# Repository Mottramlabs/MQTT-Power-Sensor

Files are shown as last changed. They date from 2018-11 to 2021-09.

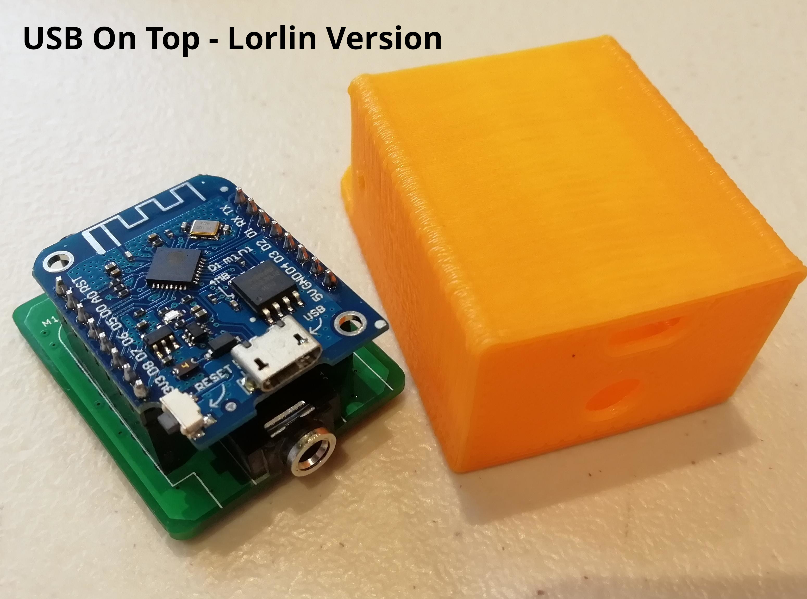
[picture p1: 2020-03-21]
3D case/Lorlin.jpg

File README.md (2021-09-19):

## ESP8266 - Power Sensor (Using a Wemos D1 Mini)

The sensor PCB uses a split core current transformer (CT) to sense the AC current flowing through a mains cable, a typical CT would be the SCT-013-000 (Current Type) capable of measuring up to 100A  available on eBay. The current transformers output is applied to a burden resistor (22 ohm) which is biased at around half of the ESP8266's supply voltage (3.3V). The ESP8266's own A/D is then used to measure voltage developed across this burned resistor.  The A/D used in the ESP8266 has an input voltage range of 0-1V but the Wemos adds a resistor divider to allow for a 0-3.3V input range to the Wemos board. 

Included are the PCB files with schematic, a simple 3D printable case and some sample firmware for the ESP8266.

###### Firmware Version 1

Using the ESP8266's own A/D (10-bit) to measure the output of the current transformer, this version measure the peak values of the mains sine wave then calculating the RMS voltage value.

###### Firmware Version 2

This is based of the EmonLib https://github.com/openenergymonitor/EmonLib library. This works different from version 1 and as some digital filtering which improves resolution at lower power levels.

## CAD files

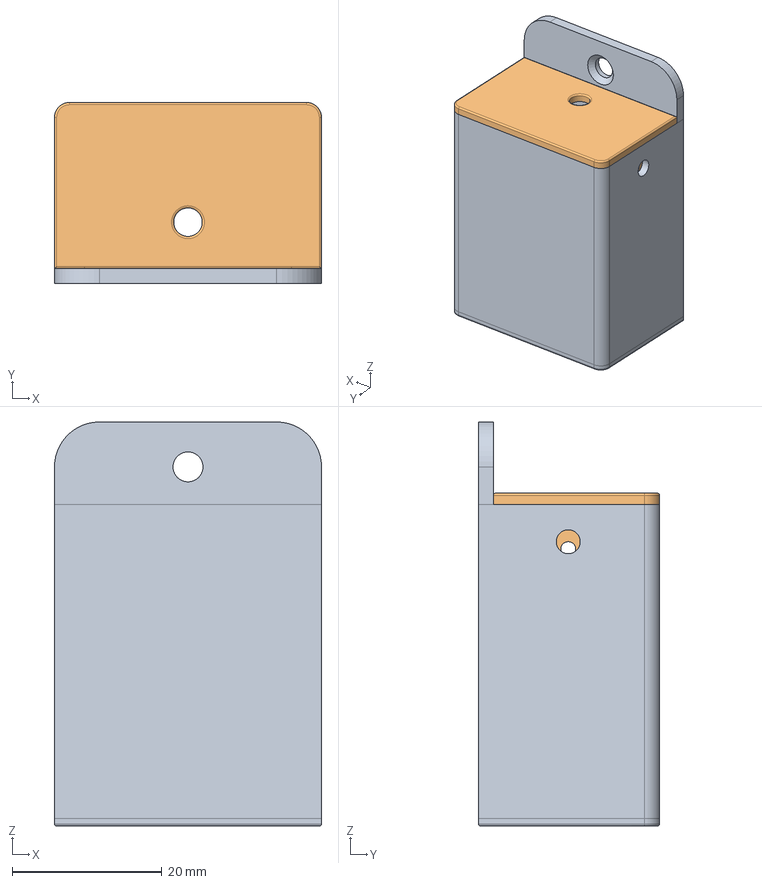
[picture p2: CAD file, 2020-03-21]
3D case/Power Sensor Lorlin Type V1.fcstd
35.7 x 24.2 x 54.0 mm
Body - Case
Body - Lid

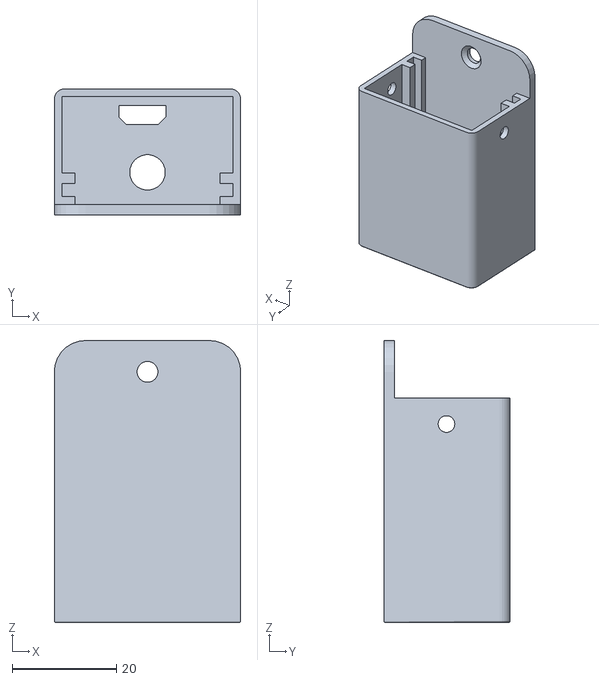
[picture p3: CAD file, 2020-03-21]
3D case/Box Lorlin Version.stl
35.7 x 24.2 x 54.0

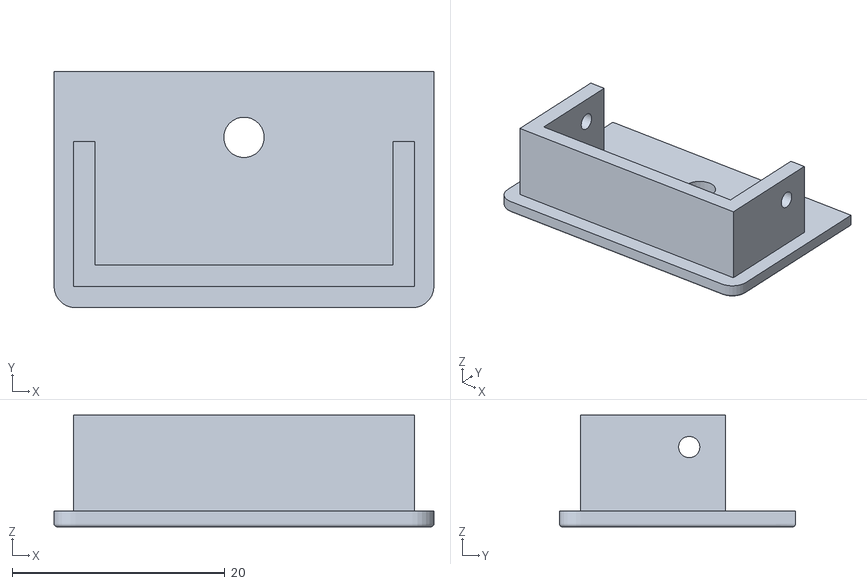
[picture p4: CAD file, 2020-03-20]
3D case/Lid.stl
35.7 x 22.2 x 10.5

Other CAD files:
3D case/Box.stl
3D case/Power Sensor V1.fcstd

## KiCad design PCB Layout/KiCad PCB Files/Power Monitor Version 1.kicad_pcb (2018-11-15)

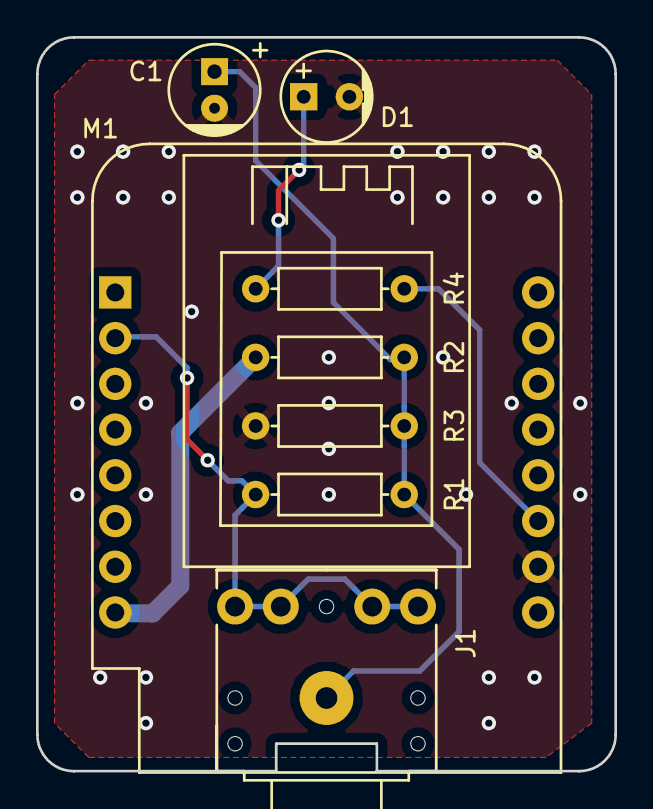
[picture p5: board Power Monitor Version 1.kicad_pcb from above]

Board: 2 copper layers, 32.1 x 40.8 mm, 8 parts (0 on the bottom side), 6 nets.

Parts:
C1: 10uF 10V; Cap_5mm_THT
D1: LED; LED 5mm
J1: 3.5mm Jack Socket - PJ-307; Jack_3.5_PJ-307
M1: Wemos_D1_Mini; Wemos D1 Mini
R1: 22R; Resistor_THT
R2, R3: 10K; Resistor_THT
R4: 1K; Resistor_THT

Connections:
+3V3: M1.8, R2.1
GND: C1.2, D1.2, M1.10, R3.2
unnamed: C1.1, J1.1, R1.2, R2.2, R3.1
unnamed: D1.1, R4.2
unnamed: J1.2, J1.3, J1.4, J1.5, M1.2, R1.1
unnamed: M1.11, R4.1

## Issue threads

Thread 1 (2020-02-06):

Board LED vs built in LED

bchris999, 2020-02-06:
On the Wemos D1 mini (recommended board), the build in LED on the wemos is on pin D4. This pin needs to be high for the onboard to be off.
The schematic has the LED on the board also on D4, however the pin need to be high for this LED to be on.
This, in effect, means that the LED on the board will be the opposite of the wemos LED.
Is this by design? Considering the availability of other (unused) pins on the Wemos.

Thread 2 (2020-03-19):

Enclosure USB cut out does not line up

neilrees, 2020-03-19:
I'm not sure if all D1 Mini boards are made equal, but the Wemos Lolin D1 Mini has the micro-usb port mounted on the top of the board when the A0 pin is on the left and D4 is on the right, the orientation required by the Power Sensor PCB.

In that orientation the micro-usb port does not line up with the cut out in the enclosure, the cut out lines up with where the port would be if the USB port were on the bottom of the board.

Would it be possible to add the CAD files for the enclosure to the repository to allow for easier editing?

Mottramlabs, 2020-03-19:
Hi Neil
Is this the board https://docs.wemos.cc/en/latest/d1/d1_mini.html ? It
appears the USB socket is on the opposite site to the D1 boards I have been
using.
The case was done using Freecad, I'll upload the files to Github and
Thingiverse.
Regards
David

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

neilrees, 2020-03-19:
Yes that's the exact one.
Much appreciated.  I'll see if I can flip the port over, if I can I'll send you a Pull Request.

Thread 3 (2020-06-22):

Getting nothing but 11w readings

beercity, 2020-06-22:
I just get 11W on the basic test sketch no matter what.
If I connect the CT, I get 11w, if I disconnect I get 11W.
If I remove the Wemos from the sensor board, still 11W

Sometimes I get 23W.  But mostly 11W, and never anything besides these two.

Board issue? Code issue? Not sure.

Mottramlabs, 2020-06-23:
Hi beercity
I'm assuming you are using the basic test sketch and the 11 is in fact 0.11 Amps. That is the softwares quiescent value (which can be trimmed to zero in the code). Anyway this is what you would see if there is no current flow through the CT or it's not plugged in. You can check the signal from the CT with a multimeter set to AC volts connected across R1 the 22R burned resistor, typical values would be 169mV AC when a load of around 4.5A is present, only approximate value without calibration.
Don't forget that the CT should be clamped across only one of the wires under test, either L or N but not both as this cancels out the signal.
David

sw1970, 2021-03-13:
Hi Mottramlabs, when you say "can be trimmed to zero in the code", do you simply mean subtract the quiescent value from the measured amount? Thanks!

Mottramlabs, 2021-03-15:
Hi sw1970
Yes you are correct, simply subract the quiescent value from the sensor. Simple way is to remove the CT from the wire under test.
David

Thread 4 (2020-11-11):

SCT-013-000 YHDC 30A 1V

excogitation, 2020-11-11:
Since I am after three tries ordering the SCT-013-000 YHDC 30A 50mA version unfortunately now the proud owner of 3 SCT-013-000 YHDC 30A 1V I was wondering if that can also be put to use through some adaption or if I simply have to get the right SCT-013 variant?

Mottramlabs, 2020-11-12:
Hi Christian

As I understand it this has the burned resistor built in, so on the PCB we
can simply remove R10, R11, R1 and R12 (the burden resistors for the
30/50mA type). I don't know the value of the internal burden resistor so
the calibration would need to be changed, but should work fine.

I have ordered one of this CT's to test.

PCB schematic

https://www.mottramlabs.com/pdf/SCH201077.pdf

Regards

David

On Wed, 11 Nov 2020 at 22:48, Christian Stöveken <notifications@github.com>
wrote:

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

edekeijzer, 2022-04-09:
> Hi Christian As I understand it this has the burned resistor built in, so on the PCB we can simply remove R10, R11, R1 and R12 (the burden resistors for the 30/50mA type). I don't know the value of the internal burden resistor so the calibration would need to be changed, but should work fine. I have ordered one of this CT's to test. PCB schematic https://www.mottramlabs.com/pdf/SCH201077.pdf Regards David
> […](#)
> On Wed, 11 Nov 2020 at 22:48, Christian Stöveken ***@***.***> wrote: Since I am after three tries ordering the SCT-013-000 YHDC 30A 50mA version unfortunately now the proud owner of 3 SCT-013-000 YHDC 30A 1V I was wondering if that can also be put to use through some adaption or if I simply have to get the right SCT-013 variant? — You are receiving this because you are subscribed to this thread. Reply to this email directly, view it on GitHub <#4>, or unsubscribe <https://github.com/notifications/unsubscribe-auth/AB67J6GZI2M7OQETRFTRMH3SPMIERANCNFSM4TSRUPPQ> .

Hi David, did you ever get into testing this? I've ordered the single sensor board as well as the 4-channel ADS1115 board a while ago and regardless of the load through my clamp, it always shows the same values.

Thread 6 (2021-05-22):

Compilation Error

Maniac0Maniac, 2021-05-22:
Hello - Perhaps a bug... Perhaps an idiot (more likely) !

My compile is failing. Completely stumped why. This is the error I'm getting:

MicroGear.cpp: In member function 'void MicroGear::syncTime(Client*, long unsigned int*)':
MicroGear.cpp:152:31: error: 'class BearSSL::WiFiClientSecure' has no member named 'verify'
  152 |             if (clientsecure->verify(tstr, gearauth)) {
      |                               ^~~~~~
exit status 1
Error compiling for board LOLIN(WEMOS) D1 R2 & mini.

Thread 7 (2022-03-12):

Poor resolution, out by a factor of ~4.7

M0LTE, 2022-03-12:
I'm running v1 firmware as a test, and I'm finding the current value is too large by a factor of about 4.7.

This is with a sensor [100A SCT-013-000](https://www.ebay.co.uk/itm/324140828103)

Is this expected? Should I just correct for this in software?

I also find the resolution is poor at the low end of the scale, e.g. I find it very hard to detect say a 40W light bulb. Normal? Anything I can do about it?

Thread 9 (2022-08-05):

Will this CT Clamp work?

That-Dude, 2022-08-05:
I have purchased (20x) 100A SCT-013-000 Non-invasive Sensor Split Core AC Current Transformer purchased from Amazon [here](https://www.amazon.co.uk/gp/product/B07MY2WHPS/ref=ppx_yo_dt_b_asin_title_o00_s00?ie=UTF8&psc=1) for a project I'm working on.

The description states "Two form of output current, voltage (voltage output built-in the sampling resistor)"

But a buyer comment states "This model does not have a resistor and as such you can decide yourself what range of current you want to have in a voltage range you can handle."

This left me confused as to whether this will work with your PCB, or if I need to remove the resistors. I purchased 20 of your PCB's this week, I wouldn't have even considered this project without them.

I don't know if this helps but I connected one of the clamps around the load of an extension cord and recorded the following voltages based on various loads that I plugged in (tip of 3.5mm plug positive, base ground).

```
13W load   = 0.030v
120W load  = 0.044v
186W load  = 0.059v
2020W load = 0.430v
```

sachasmart, 2025-02-01:
Any hints for future visitors?

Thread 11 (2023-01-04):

Incorrect values being reported

CplSyx, 2023-01-04:
Using the clamp [SCT-013-000](https://www.amazon.co.uk/dp/B08CDMVK2V/ref=pe_27063361_487055811_TE_3p_dp_1) and v2 of the firmware, I connect the clamp to my mains supply and obtain values of 38~40 being reported by the software output.

If the comment to [Issue 3](https://github.com/Mottramlabs/MQTT-Power-Sensor/issues/3) holds true for firmware v2, I believe that indicates 0.38-0.4 A - which is incorrect as I have other devices drawing more than that at present.
Additionally when turning on a known load of 8.3A (a heater), that reading jumps to ~178, which would be 1.78A. That's also incorrect.
Even assuming that the values are raw within the 0-1024 range of the ADC, then 38 => 3.7A and 178 => 17.3A which is also incorrect as I'd expect a value change of around 85 and not 140.

I have tested the D1 board I am using and it correctly reads from the ADC A0 pin within the 0-1024 range at 0-3.3V, and the clamp is definitely picking up a change in current draw so I assume this is an issue within the firmware but I cannot determine where.

Looking for some advice as to where I could be going wrong please @Mottramlabs

CplSyx, 2023-06-09:
@Scoff123 I didn't get a response from the creator so I started pulling apart the code myself. I've reworked the entire thing in a forked repo (starting from the base Emonlib).

I had some issues with home assistant (unrelated to this) which means I've not been able to actually hook it in yet as I'm sorting out zigbee sensor issues, hence that part of the documentation being missing.
However the test data using a reference load is now correct.

Scoff123, 2023-06-09:
@CplSyx  Thanks for taking the time to respond. That's good to hear - would you be happy for me to use your reworked code in my setup? I'm just figuring out how I can use the clamp to monitor just the phase line in my 2 core + earth, but once I've got that sorted I can put this all together.

CplSyx, 2023-06-09:
@Scoff123 Yes of course, feel free to use / alter as you wish.

If you can strip the outer sheath from section of your twin + earth, you can put the clamp over the live wire.

Scoff123, 2023-06-23:
@CplSyx  Hi thanks very much. I'm having a couple of compile issues using the firmware.ino that you have on your repo. I wasn't sure how to contact you? I've downloaded the necessary libraries but the .ino won't compile due to not finding some header files relating to ESPAsyncWebServer...

CplSyx, 2023-06-23:
@Scoff123 In the [Readme.md](https://github.com/CplSyx/MQTT-Power-Sensor-HomeAssistant/blob/master/README.md) I've referenced the libraries you need - copied here for simplicity:

- ESPAsyncTCP by me-no-dev (via GitHub [here](https://github.com/me-no-dev/ESPAsyncTCP))
- ESPAsyncWebServer by me-no-dev (via GitHub [here](https://github.com/me-no-dev/ESPAsyncWebServer))

Assuming you're using the Arduino IDE you can download the latest releases of those libraries and then install them by going to
`Sketch > Include Library > Add .zip Library`

Hope that helps!

Scoff123, 2023-06-23:
@CplSyx  Thanks - I did read through the readme file and followed the required libraries and installed them with library manager within the Arduino IDE.
I'm getting the following error during compile:

c:/users/thinkpadx260/appdata/local/arduino15/packages/esp8266/tools/xtensa-lx106-elf-gcc/3.1.0-gcc10.3-e5f9fec/bin/../lib/gcc/xtensa-lx106-elf/10.3.0/../../../../xtensa-lx106-elf/bin/ld.exe: C:\Users\ThinkPadX260\AppData\Local\Temp\arduino\sketches\CED1DDF4214782B6EE214442A04C06BF\libraries\EmonLib\EmonLib_CurrentOnly.cpp.o: in function `_ZN13EnergyMonitor7currentEjd':
C:\Users\ThinkPadX260\Documents\Arduino\libraries\EmonLib/EmonLib_CurrentOnly.cpp:31: multiple definition of `_ZN13EnergyMonitor7currentEjd'; C:\Users\ThinkPadX260\AppData\Local\Temp\arduino\sketches\CED1DDF4214782B6EE214442A04C06BF\libraries\EmonLib\EmonLib.cpp.o:C:\Users\ThinkPadX260\Documents\Arduino\libraries\EmonLib/EmonLib.cpp:36: first defined here
c:/users/thinkpadx260/appdata/local/arduino15/packages/esp8266/tools/xtensa-lx106-elf-gcc/3.1.0-gcc10.3-e5f9fec/bin/../lib/gcc/xtensa-lx106-elf/10.3.0/../../../../xtensa-lx106-elf/bin/ld.exe: C:\Users\ThinkPadX260\AppData\Local\Temp\arduino\sketches\CED1DDF4214782B6EE214442A04C06BF\libraries\EmonLib\EmonLib_CurrentOnly.cpp.o: in function `_ZN13EnergyMonitor8calcIrmsEj':
C:\Users\ThinkPadX260\Documents\Arduino\libraries\EmonLib/EmonLib_CurrentOnly.cpp:52: multiple definition of `_ZN13EnergyMonitor8calcIrmsEj'; C:\Users\ThinkPadX260\AppData\Local\Temp\arduino\sketches\CED1DDF4214782B6EE214442A04C06BF\libraries\EmonLib\EmonLib.cpp.o:C:\Users\ThinkPadX260\Documents\Arduino\libraries\EmonLib/EmonLib.cpp:178: first defined here
c:/users/thinkpadx260/appdata/local/arduino15/packages/esp8266/tools/xtensa-lx106-elf-gcc/3.1.0-gcc10.3-e5f9fec/bin/../lib/gcc/xtensa-lx106-elf/10.3.0/../../../../xtensa-lx106-elf/bin/ld.exe: C:\Users\ThinkPadX260\AppData\Local\Temp\arduino\sketches\CED1DDF4214782B6EE214442A04C06BF\libraries\EmonLib\EmonLib_CurrentOnly.cpp.o: in function `_ZN13EnergyMonitor11serialprintEv':
C:\Users\ThinkPadX260\Documents\Arduino\libraries\EmonLib/EmonLib_CurrentOnly.cpp:81: multiple definition of `_ZN13EnergyMonitor11serialprintEv'; C:\Users\ThinkPadX260\AppData\Local\Temp\arduino\sketches\CED1DDF4214782B6EE214442A04C06BF\libraries\EmonLib\EmonLib.cpp.o:C:\Users\ThinkPadX260\Documents\Arduino\libraries\EmonLib/EmonLib.cpp:214: first defined here
collect2.exe: error: ld returned 1 exit status

exit status 1

Any ideas what might be going on?

Scoff123, 2023-06-23:
Ignore me, it was the original EmonLib files that I thought I had moved out of the libraries folder, but they were actually in another sub folder still within the libraries folder. Problem solved :)

sachasmart, 2025-02-02:
@CplSyx Thanks for pulling this together. I have it up and running although (forgive me), having some difficulty understanding this.

sachasmart, 2025-02-02:
@CplSyx Thanks for pulling this together. I have it up and running although (forgive me), having some difficulty understanding this.

The value (`Value`) that is being published is the `Irms` (the root mean square) of current in an alternating current (AC). As I live in Canada, to determine power (Vrms), I need to multiple the `Irms` by 120V, correct? Thereby, the equation is:
```
power = Irms * 120V
```

If I clamp the CT clamp to a known source (100W), my `Irms` values are ~0.03-0.15. Power is `Irms * 120V`.. Frankly, if I unplug the CT clamp the values are still within that range..

Any suggestions?

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

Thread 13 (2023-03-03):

Missing KiCad Libs

jnissen, 2023-03-03:
Hello,
I want do Load the Project in Kicad. But there are symbol Libs missing.

Can yout add the Libs ?

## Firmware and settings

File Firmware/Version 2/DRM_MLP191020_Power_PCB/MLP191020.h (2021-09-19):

/***************************************************************************************************************************/
/*
    A simple library that reads an MLP191020 - 1-channel CT sesnor boards
    Based On:   EmonLib https://github.com/openenergymonitor/EmonLib
    Auther:     David Mottram
    Updated:    4th September 2021
*/
/***************************************************************************************************************************/

#ifndef MLP191020_Lib
#define MLP191020_Lib

// check of legacy IDE
#if ARDUINO >= 100
#include "Arduino.h"
#else
#include "WProgram.h"
#endif

class MLP191020
{
  public:

    MLP191020(double _ICAL);
    double power_sample();

  private:

    #define Samples_Taken 400                                   // sample to be taken per channel, 1000 is approx 100mS or 5 cycles @ 50Hz
    const float Calibration = 1;                                // calibration value
    const float Volts_Conv = ((2.048 / 0.512) / Calibration);   // volts conversion value A/D 12-bit

    #define Mux_delay 500                                       // delay in uS to allow mux to settle
    #define AD_delay 1000                                       // A/D delay in uS 

    // new bits
    double ICAL;
    int sampleI;                                                // sample_ holds the raw analog read value

    double offsetI = 320;                                       // low-pass filter output
    double Irms;                                                // useful value variables
    double filteredI;                                           // filtered_ is the raw analog value minus the DC offset
    double sqI, sumI;                                           // sq = squared, sum = Sum
    #define SupplyVoltage 3.3                                   // supply voltage 3.3V
    #define ADC_COUNTS 1024                                     // 10-bit A/D

};
#endif

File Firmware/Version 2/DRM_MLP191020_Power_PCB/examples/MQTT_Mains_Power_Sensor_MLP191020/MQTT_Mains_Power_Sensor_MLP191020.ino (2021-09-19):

/*
    Title:        MQTT 1 Way Mains Power Sensor Demo
    Date:         4th September 2021
    Version:      1
    Description:  Sample code
    Device:       ESP8266
    WiFi:		  See "WiFi_Settings.h" for wifi AP and password
    MQTT:		  See "MQTT_Settings.h" for MQTT broker and topic
*/

/* ********************************** Compiler settings, un-comment to use ************************** */
//#define Fixed_IP                      // un-comment to use a fixed IP address to speed up development
//#ifdef Watchdog_ON                    // watchdog items, comment out if not used
//#define Print_Report_Level_1          // un-comment for option
#define Print_Report_Level_2          // un-comment for option, report received MQTT message
#define Print_Report_Level_3          // un-comment for option
/* ************************************************************************************************** */

#include <ESP8266WiFi.h>              // needed for EPS8266
#include <WiFiClient.h>               // WiFi client

// custom settings files
#include "Wifi_Settings.h"            // custom Wifi settings
#include "MQTT_Settings.h"            // MQTT broker and topic
#include "Project_Settings.h"         // board specific details.

// incude WiFi and MQTT functions
WiFiClient espClient;                 // for ESP8266 boards
#include <PubSubClient.h>             // http://pubsubclient.knolleary.net/api.html
PubSubClient client(espClient);       // ESP pubsub client
#include "WiFi_Functions.h"           // read wifi data
#include "MQTT_Functions.h"           // MQTT Functions

// library for the MLP191020 PCB
#include <MLP191020.h>
// make an instance of MLP191020
MLP191020 My_PCB(Cal_value);


void setup() {

#ifdef Watchdog_ON
  // watchdog items, comment out if not used
  secondTick.attach(1, ISRwatchdog);
#endif

  // I/O
  pinMode(Network_LED, OUTPUT);
  digitalWrite(Network_LED, LOW);

  // connect to WiFi access point
  Get_Wifi();

  // connect to the MQTT broker
  client.setServer(mqtt_server, 1883);
  client.setCallback(callback);

  // reset heartbeat timer
  LastMsg = millis();

} // end of setup


void loop() {

  if (!client.connected()) {
    reconnect();
  } // end if
  client.loop();

  // read A/D values and store in value
    Value = My_PCB.power_sample();

  // headbeat or report requested
  if (millis() - LastMsg > Heatbeat || Report_Request == 1) {

    LastMsg = millis();
    Report_Request = 0;

    // update event progress counter
    ++Heart_Value;
    if (Heart_Value > Heartbeat_Range) {
      Heart_Value = 1;
    } // end if

    // heartbeat timed out or report message requested

    // get a report make and make as an array
    String Report = Status_Report();
    char Report_array[(Report.length() + 1)];
    Report.toCharArray(Report_array, (Report.length() + 1));

#ifdef Print_Report_Level_2
    // display a report when publishing
    Serial.print("Published To topic: "); Serial.print(InStatus); Serial.print("  -  Report Sent: "); Serial.println(Report_array);
#endif

    digitalWrite(Network_LED, HIGH);
    // send a status report
    client.publish(InStatus, Report_array);

    // only used to make the LED flash visable
    delay(10);

    digitalWrite(Network_LED, LOW);

  } // end of heartbeat timer

} // end of loop
